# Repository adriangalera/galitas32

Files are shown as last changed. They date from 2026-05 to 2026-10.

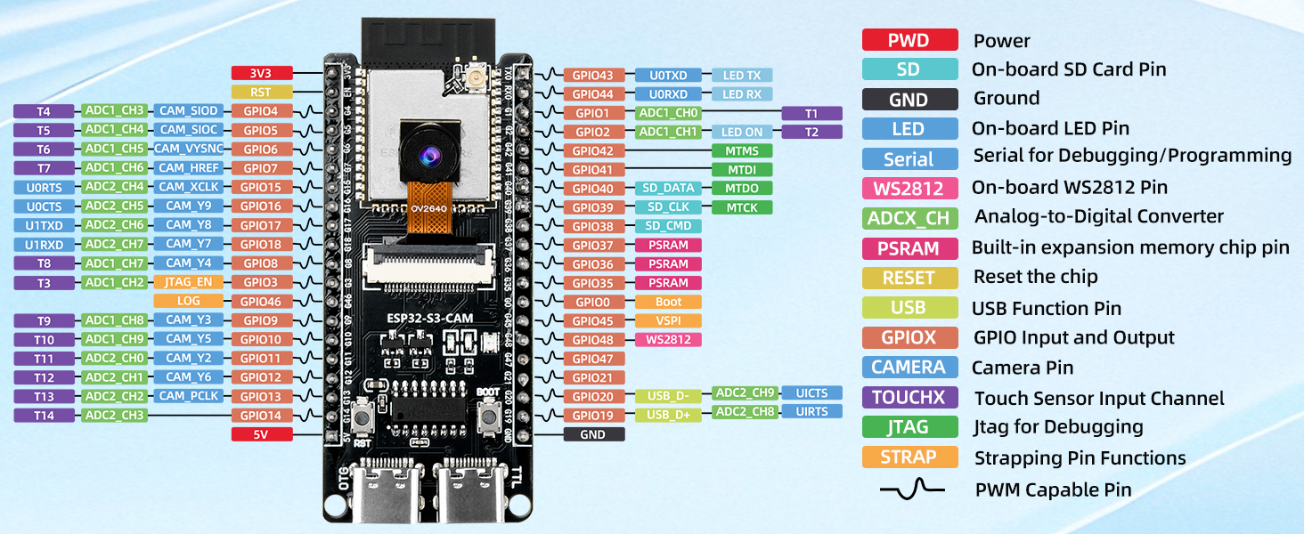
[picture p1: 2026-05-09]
pinout.jpg

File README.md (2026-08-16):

# galitas32

Home alarm built with ESP32

Features:

- Read door sensor
- Camera to store/send images
- Buzzer to scare burglars
- LED strip with programmable colors
- RFID to lock/unlock the alarm
- Connected to MQTT to interact with the system via telegram, through a Raspberry Pi acting as MQTT Broker and Telegram bot.

This is built using [ESP32-S3-CAM board](https://www.amazon.es/dp/B0F4D8ZY6L?ref=ppx_yo2ov_dt_b_fed_asin_title&th=1). 

Built with [PlatformIO](https://docs.platformio.org/en/latest/)

## Requirements

The physical mechanisms must work regardless of the network connection, i.e: door sensor, LED strip, camera, RFID reader and speaker. 

When the network is enabled, it will act as an enhacement.

> `*` optional steps (the alarm will still work without them)

### Startup procedure

1. Setup read sensor
2. Setup LED strip
3. Setup camera
4. Setup RFID reader
5. Setup speaker
6. `*`Setup Wifi
7. `*`Setup MQTT
8. Determine the lock status: armed/disarmed

### Door sensor

When the door is open:

- The LED strip is powered, the color depends on the lock status:
    - Armed: blinking red/blue like a policen siren
    - Disarmed: welcoming color: light orange or something like this

- Camera takes pictures for 30 seconds one picture each second:
    - Armed: send the pictures via MQTT (to telegram) and store the images in the SD
    - Disarmed: store the images in the SD

- Speaker: 
    - Armed: powered and making noises
    - Disarmed: do nothing

- `*` MQTT:
    - Armed: While open send message about door opened
    - Disarmed: While open send message about door opened

When the door is closed:

- LED strip: powered down
- Camera: stop take pictures task (if running)
- Speaker: powered down
- MQTT: stop sending message task

### RFID reader

The RFID read will be used to toogle the status and deactivate the alerting devices when the alarm is armed:

When the RFID tag is detected in the reader:
- Disarmed: 
    - Set the alarm in armed state
    - Send a message about the state toggling `*`

- Armed:
    - Set the alarm in disarmed state
    - Send a message about the state toggling `*`
    - The alerting devices will see the disarmed state

## Wirings

### Door sensor

```text

ESP32
-------
   Common GND -------------------------------+
                                             |
   D2 (input pin)                            |
        |                                    |
        |                                    |
        +--------------------[ REED SWITCH ]+
                             (magnet closes contact)
```

### LED Strip

```text

External 5V Power Supply
------------------------
    +5V ----------------------------+------------------> LED Strip +5V
                                    |
    GND ----------------------------+------------------> LED Strip GND
                                    |
                                    +------------------> Common GND

ESP32
-------
   D6 (data pin)
        |
        |   330Ω (recommended)
        +----/\/\/\/\-------------------------> DIN (LED Strip Data In)
```

There's an external power source providing 5V for the LED strip. The GND should be common with the ESP32 board.

The LED strip needs to be programmed through the Data In line. Therefore the output pin of the ESP32 will be connected to DIN port in the LED strip. The resistor protects the pin from current surges caused by the LED strip.

### Buzzer

```text
    ESP
    --------
        PIN 21
        |
        |   1kΩ
        +---/\/\/\----+
                        |
                        |
                    B |/
GND ---------------- |   TIP120
                    C |\ 
                        |
                        +--------(-) Buzzer (+)-------- +5V
                        |
                    E  |
                        |
                        GND
```

**Base**: connected with the ESP32 PIN via a 1K resistor for protection.

**Collector**: connected to the negative side of the buzzer. This acts as the switch to close the circuit when the base has signal coming from ESP32.

**Emitter**: connected to GND

## Case

The 3D design of the case it is AI-enabled. Make sure to install:

```bash
brew install admesh
pip3 install trimesh rtree scipy
```

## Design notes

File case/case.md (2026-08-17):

# Especificación completa para agente IA — Carcasa 3D para alarma ESP32-S3

Diseña una **carcasa imprimible en 3D para un sistema de alarma doméstico DIY basado en ESP32-S3**, destinada a ser modificada posteriormente en **Tinkercad** e impresa mediante FDM en una **Artillery Genius**.

Estas instrucciones consolidan las decisiones de diseño tomadas hasta ahora. **No deben revertirse decisiones ya establecidas**, especialmente la posición inferior de los conectores, los buses verticales separados, el sistema de cámara y la entrada inferior del cable USB.

El objetivo no es simplemente producir STL visualmente correctos: el conjunto debe ser **mecánicamente montable, desmontable, imprimible y verificable**.

---

# 1. Objetivo estético

La carcasa debe parecer un **detector fotográfico de alarma comercial montado en pared**, no una caja rectangular genérica para proyectos Arduino.

Puede utilizarse como inspiración general el lenguaje visual de detectores fotográficos de sistemas como Verisure/Securitas Direct, pero **sin copiar exactamente ningún producto comercial**.

Dimensiones exteriores objetivo aproximadas:

* Alto: **190 mm**
* Ancho: **74 mm**
* Profundidad: **44 mm**

Características visuales:

* Formato vertical
* Laterales redondeados
* Parte superior redondeada
* Parte inferior redondeada
* Frontal ligeramente convexo/suavizado
* Superficies exteriores limpias
* Cámara en la zona superior
* Sin electrónica visible
* Sin rejillas de ventilación visibles en el frontal
* Sin tornillos visibles desde el frontal
* Sin estructuras mecánicas sobresaliendo por la superficie frontal

Priorizar una apariencia de **producto de consumo terminado**.

---

# 2. Componentes principales

El diseño debe incluir como mínimo:

1. `front_shell.stl`
2. `rear_shell.stl`
3. `camera_cradle.stl`
4. `dupont_insert_2pin.stl`
5. `dupont_insert_3pin.stl`
6. `dupont_insert_4pin.stl`
7. `dupont_insert_6pin.stl`

También es recomendable incluir:

8. `dupont_insert_blank.stl`
9. `camera_angle_gauge.stl`

Debe entregarse además el archivo paramétrico:

`alarm_case.scad`

---

# 3. Arquitectura frontal/trasera

La carcasa se divide en dos piezas principales:

* Frontal desmontable
* Trasera fija

La arquitectura de mantenimiento debe permitir que **la trasera permanezca montada en la pared al abrir la alarma**.

La mayor parte de la electrónica debe permanecer en la trasera:

* ESP32-S3
* Buses +5 V y GND
* Conectores Dupont
* Cableado de periféricos
* Electrónica auxiliar
* Driver/MOSFET de sirena

El frontal debe contener principalmente:

* Cámara
* Cradle de cámara
* Mecanismo de ajuste

Idealmente, el único enlace eléctrico que debe permanecer entre frontal y trasera al abrir la caja es el **ribbon de la OV2640**.

---

# 4. Sistema de cierre

La carcasa debe cerrarse mediante:

* Dos ganchos superiores
* Dos tornillos M3 inferiores

Procedimiento:

1. Introducir los dos ganchos superiores del frontal en los catches de la trasera.
2. Girar/bascular el frontal hacia la posición cerrada.
3. Introducir dos tornillos M3 desde la parte trasera/inferior.
4. Los tornillos roscan en insertos térmicos M3 instalados en bosses del frontal.

Los ganchos deben **solaparse físicamente** con los catches.

No crear ganchos puramente decorativos que solamente queden cerca de los receptores.

Los tornillos M3 deben:

* Atravesar plástico sólido de la trasera
* Estar alineados con los bosses del frontal
* Tener las cabezas recesadas
* No ser visibles desde el frontal

---

# 5. Insertos térmicos

El usuario dispone de insertos térmicos:

* M2
* M2.5
* M3
* M4
* M5
* M6

Usar:

* **M3 para el cierre principal**
* **M2.5 para el mecanismo ajustable de cámara**

No asumir que el diámetro nominal del inserto es el diámetro correcto del agujero impreso.

Parametrizar explícitamente:

* `m3_clearance`
* `m3_insert_pilot`
* `m25_clearance`
* `m25_insert_pilot`, si se utiliza inserto en el mecanismo

---

# 6. Frontal

El frontal debe incluir:

* Apertura de cámara
* Dos ganchos superiores
* Dos bosses inferiores para M3
* Soportes internos de cámara

La superficie exterior debe permanecer limpia.

## Restricción crítica

**Ninguna geometría de soporte de cámara puede atravesar la superficie exterior frontal.**

Esto incluye:

* Pivot supports
* Bosses
* Brackets
* Locking slot
* Refuerzos
* Orejetas
* Tornillos

Todos deben permanecer detrás de la superficie interior.

La única penetración relacionada con la cámara será la **apertura óptica**.

---

# 7. Cámara OV2640

La cámara es una **OV2640** conectada mediante ribbon al ESP32-S3.

Debe apuntar hacia abajo porque el dispositivo estará instalado verticalmente en una pared.

Rango de ajuste:

* **10° downward mínimo**
* **20° downward posición nominal**
* **35° downward máximo**

El cradle debe poder detenerse en cualquier posición razonable dentro de ese intervalo mediante un tornillo de bloqueo.

---

# 8. Pivote de cámara

Utilizar un eje horizontal.

Debe existir:

* Soporte fijo izquierdo
* Cradle
* Soporte fijo derecho

Un tornillo/eje **M2.5** debe poder atravesar físicamente:

```text
soporte izquierdo
       ↓
     cradle
       ↓
soporte derecho
```

Los tres agujeros deben ser:

* Coaxiales
* Correctamente alineados
* Con holgura adecuada

No diseñar dos pivotes independientes que no compartan exactamente el mismo eje.

---

# 9. Bloqueo angular

El sistema de bloqueo debe existir en **un solo lateral**.

Utilizar:

* Slot curvo
* Tornillo M2.5

El lateral opuesto debe ser únicamente pivote.

No crear dos slots de bloqueo.

El slot debe:

* Tener el mismo centro geométrico que el pivote
* Seguir correctamente la dirección real de rotación
* Cubrir aproximadamente 10°–35°
* Tener suficiente material alrededor

---

# 10. Apertura óptica

No utilizar un túnel circular estrecho.

La abertura debe admitir el campo de visión de la cámara en todo el rango de movimiento.

Puede ser:

* Verticalmente alargada
* Ovalada
* Chamfered internamente
* Recesada

Debe comprobarse como mínimo a:

* 10°
* 15°
* 20°
* 25°
* 30°
* 35°

---

# 11. Ribbon OV2640

Debe existir una ruta realista para el ribbon.

No debe:

* Pasar por el eje del pivote
* Ser pinzado al cerrar la carcasa
* Rozar aristas afiladas
* Interferir con el tornillo de bloqueo
* Quedar excesivamente doblado
* Impedir el movimiento del cradle

Dejar suficiente volumen detrás/debajo de la cámara para formar una curva suave.

---

# 12. ESP32-S3

Controlador:

**ESP32-S3 WROOM N16R8 camera development board con OV2640**

Dimensiones aproximadas del PCB:

**57.1 × 28.2 mm**

No diseñar un pocket de fricción exacta.

Añadir holgura para:

* PCB
* Pines
* Headers
* Dupont
* USB-C
* microSD
* Ribbon
* Cableado

---

# 13. Cradle del ESP32

La placa debe estar montada en la **trasera**.

Utilizar un sistema desmontable mediante:

* Rails
* Clips
* Posts
* Retenedores equivalentes

El cradle central utilizado hasta ahora es conceptualmente válido.

La placa debe poder retirarse para mantenimiento.

No atraparla permanentemente entre estructuras impresas.

---

# 14. Acceso USB-C y microSD del ESP32

Aunque exista una entrada independiente para alimentación general, debe mantenerse espacio para acceder al:

* USB-C del ESP32
* microSD

Verificar físicamente que:

* Puede conectarse un cable USB-C
* Los buses no bloquean el conector
* Los Dupont no bloquean el conector
* La placa puede retirarse
* La microSD tiene espacio razonable para inserción/extracción

---

# 15. Organización general de la trasera

La distribución preferida de arriba hacia abajo es:

```text
┌─────────────────────────────┐
│     CATCHES / WALL MOUNT    │
│                             │
│        ZONA CÁMARA          │
│                             │
│ +5V       ESP32       GND   │
│  ║          │          ║    │
│  ║          │          ║    │
│  ║          │          ║    │
│  ║                     ║    │
│                             │
│    ZONA AUXILIAR/BUZZER     │
│                             │
│ [BAY] [BAY] [BAY] [BAY]    │
│                             │
│ M3      USB POWER      M3   │
└────────────┬────────────────┘
             │
             ▼
          cable USB
```

La representación es conceptual y puede ajustarse para evitar interferencias.

---

# 16. Eliminar elementos innecesarios

No volver a introducir las protuberancias extrañas presentes en versiones iniciales.

Evitar:

* Cable loops laterales voluminosos
* Shelves arbitrarios
* Bosses sin función
* Soportes decorativos
* Estructuras laterales innecesarias
* Grandes bandejas dedicadas a un único componente

Mantener el interior limpio.

---

# 17. Alimentación general

El sistema utilizará **5 V**.

No asumir que toda la corriente de los periféricos debe circular a través del ESP32.

Arquitectura:

```text
              ENTRADA 5 V
                  │
          ┌───────┴───────┐
          │               │
       BUS +5V         BUS GND
          │               │
    ┌─────┼─────┐    ┌────┼─────┐
    │     │     │    │    │     │
 ESP32  RFID   LED  ESP32 RFID  LED
          │               │
       DRIVER          SIRENA
```

El ESP32 es una rama de alimentación más.

---

# 18. Sirena

La corriente de una sirena no debe ser suministrada directamente por un GPIO.

Utilizar:

* MOSFET
* Transistor
* Driver equivalente

El GPIO solamente proporciona la señal de control.

Debe existir espacio interior para este pequeño circuito.

---

# 19. Buses de alimentación

La trasera debe incorporar soportes para dos buses independientes:

* `+5V`
* `GND`

Los buses deben estar dispuestos **verticalmente**.

Configuración consolidada:

* `+5V` en el lateral interior izquierdo
* `GND` en el lateral interior derecho

No colocar ambos buses juntos.

---

# 20. Separación física de buses

Separarlos tanto como sea razonable dentro de la carcasa.

Objetivo aproximado:

**55–60 mm entre ejes**, si la geometría lo permite.

La razón principal es mecánica y de seguridad:

* Evitar puentes de estaño
* Evitar cortos accidentales
* Evitar tocar simultáneamente ambos buses con herramientas
* Facilitar soldadura y mantenimiento

---

# 21. Orientación vertical

No colocar los buses horizontalmente.

Aprovechar la altura de aproximadamente 190 mm.

Conceptualmente:

```text
+5V                          GND
 ║                            ║
 ╠── ESP32 5V        ESP32 ───╣
 ║                            ║
 ╠── RFID 5V          RFID ───╣
 ║                            ║
 ╠── LED 5V            LED ───╣
 ║                            ║
 ╠── DRIVER          DRIVER ───╣
 ║                            ║
 ╚── etc.              etc. ───╣
```

Las señales pueden circular principalmente por la zona central.

---

# 22. Material de los buses

Los buses pueden realizarse mediante:

* Hilo de cobre rígido
* Barra fina de cobre
* Conductor rígido equivalente

No aplicar estaño directamente sobre la pared de PLA/PETG.

El plástico solamente debe proporcionar **soporte mecánico y aislamiento**.

---

# 23. Clips para buses

Crear pequeños clips integrados en la trasera.

Características:

* Aproximadamente 4–6 clips por bus
* Distribuidos verticalmente
* Separación aproximada 20–30 mm
* Apertura hacia el **centro de la carcasa**

La apertura hacia el centro permite colocar el conductor lateralmente:

```text
PARED             INTERIOR

│   ┌──
│   │ ●  ← cobre
│   └──
│
```

No utilizar una sucesión de agujeros cerrados que obligue a introducir el conductor longitudinalmente.

---

# 24. Parámetros del bus

Parametrizar:

* `bus_wire_diameter`
* `bus_wire_clearance`
* `bus_clip_spacing`
* `bus_left_position`
* `bus_right_position`
* `bus_start_height`
* `bus_end_height`

Valor inicial orientativo:

`bus_wire_diameter = 1.6 mm`

El usuario deberá poder cambiarlo después de medir el conductor real.

---

# 25. Longitud de los buses

No extenderlos hasta la parte superior de la carcasa si no es necesario.

Deben:

* Comenzar debajo de la zona de cámara
* Recorrer la zona útil de electrónica
* Terminar antes de la zona inferior donde puedan interferir con Dupont, USB o M3

---

# 26. Kit Dupont disponible

El usuario dispone de un kit estándar Dupont de **2.54 mm** que permite fabricar conectores mediante crimpado.

Dispone de:

* Terminales macho
* Terminales hembra
* Carcasas multipin

Por tanto, aprovechar **conectores Dupont eléctricos reales**.

---

# 27. Arquitectura de conectores externos

La solución preferida es:

### Periférico

Cable terminado en **conector Dupont macho multipin**.

### Carcasa

Conector **Dupont hembra multipin** sujeto mecánicamente mediante un insert impreso.

Conceptualmente:

```text
EXTERIOR                   INTERIOR

Periférico
    │
┌───────────┐
│ DUPONT    │
│ MACHO     │
└──●─●─●────┘
   ↓ ↓ ↓
┌──○─○─○────┐
│ DUPONT    │
│ HEMBRA    │
└───────────┘
█████████████ ← insert/retención impresa
    │ │ │
    │ │ └── señal
    │ └──── GND
    └────── +5V
```

---

# 28. Función del insert Dupont

El plástico impreso **no sustituye el conector Dupont**.

Su función es exclusivamente:

* Sujetar la carcasa Dupont hembra
* Evitar que se introduzca hacia dentro
* Evitar que salga hacia fuera
* Resistir las fuerzas de conexión/desconexión

Debe poder retirarse durante mantenimiento.

---

# 29. Inserts Dupont requeridos

Crear:

* 2P
* 3P
* 4P
* 6P

También es recomendable:

* Insert ciego

---

# 30. Bahías modulares

Preferir varias bahías con **geometría externa común**.

Cada bahía debería poder recibir distintos inserts.

Por ejemplo:

```text
[BAY 1] [BAY 2] [BAY 3] [BAY 4]
```

y cada una podría utilizar:

* 2P
* 3P
* 4P
* 6P
* Blank

si la solución mecánica lo permite.

---

# 31. Ubicación de Dupont

Esta decisión es obligatoria:

**Todos los conectores Dupont externos deben encontrarse en la parte inferior de la trasera.**

No colocarlos:

* Junto al ESP32
* En mitad de la carcasa
* En la zona superior
* Dispersos por los laterales

Los cables externos deben poder salir naturalmente hacia abajo.

---

# 32. Cableado de Dupont

Ejemplo RFID 6P:

```text
+5V  ─────────► BUS +5V
GND  ─────────► BUS GND
SCK  ─────────► ESP32
MOSI ─────────► ESP32
MISO ─────────► ESP32
CS   ─────────► ESP32
```

Los conductores de alimentación se dirigen a los laterales.

Las señales pueden subir por la zona central.

---

# 33. Entrada USB de alimentación

Debe existir una abertura específica para introducir desde el exterior el **cable USB utilizado como alimentación principal de 5 V**.

Esta entrada es independiente de:

* Los conectores Dupont
* El USB-C de programación del ESP32

---

# 34. Posición del USB de alimentación

Situar la entrada en la **parte inferior**, preferiblemente centrada aproximadamente entre los dos tornillos M3 cuando la geometría lo permita.

Conceptualmente:

```text
│ [DUPONT] [DUPONT] [DUPONT] │
│                             │
│ M3      USB POWER       M3  │
└────────────┬────────────────┘
             │
             ▼
           cable
```

El cable debe salir naturalmente hacia abajo.

---

# 35. Apertura USB

La abertura debe permitir introducir **la cabeza completa del conector USB**, no únicamente el diámetro del cable.

Valor inicial orientativo utilizado:

* Ancho: aproximadamente **16 mm**
* Alto: aproximadamente **10 mm**
* Holgura adicional: aproximadamente **0.8 mm**

Estos valores **no son definitivos**.

Deben quedar parametrizados porque el usuario medirá posteriormente su cable real.

Crear:

* `usb_cable_hole_width`
* `usb_cable_hole_height`
* `usb_cable_clearance`
* `usb_cable_hole_position`

---

# 36. Forma de la entrada USB

Preferir una abertura/muesca accesible desde la parte inferior en lugar de un simple agujero circular.

La sustitución del cable debe ser sencilla.

Evitar obligar al usuario a:

* Cortar el cable
* Desoldarlo para retirarlo
* Desmontar innecesariamente toda la electrónica

---

# 37. Strain relief USB

Incorporar alivio de tensión interior.

Solución preferida:

**dos pequeños puntos/loops/posts para una brida**.

La brida debe sujetar el cable después de entrar en la carcasa.

Así:

```text
exterior
   │
   │ cable
   ▼
[entrada USB]
   │
   ├────(brida)────┐
   │               │
   └───────────────┘
         │
         ├── +5V → bus +5V
         └── GND → bus GND
```

Un tirón exterior no debe transmitirse directamente a las soldaduras.

---

# 38. Entrada USB vs USB-C ESP32

Distinguir claramente:

### Entrada USB principal

Proporciona alimentación general de 5 V al sistema.

### USB-C ESP32

Se utiliza para:

* Programación
* Depuración
* Alimentación alternativa cuando proceda

El diseño no debe confundir ambos.

---

# 39. Buzzer SFM-27

Debe reservarse espacio para un buzzer aproximadamente:

**SFM-27, ~30 × 15 mm**

No utilizar únicamente sus dimensiones nominales.

Reservar un volumen aproximado de al menos:

**35 × 20 × 20 mm**

para incluir:

* Cuerpo
* Terminales
* Soldaduras
* Cables
* Holgura de montaje

---

# 40. Posición del buzzer

Preferir una zona libre:

* Entre cámara y ESP32, si existe suficiente profundidad
* O en otra zona interna libre que no interfiera con los buses

No bloquear:

* Cámara
* Ribbon
* ESP32
* USB-C
* microSD
* Dupont
* Buses

---

# 41. Retención del buzzer

No volver a crear una gran bandeja/shelf como en diseños anteriores.

Si se proporciona retención específica, utilizar algo mínimo:

* 2–3 pequeños clips
* Topes
* Clip + tope
* Sistema equivalente

El buzzer debe ser **desmontable**.

No pegarlo permanentemente ni atraparlo entre las dos mitades.

---

# 42. Validación específica del buzzer

Antes de finalizar, comprobar con un volumen de referencia de al menos:

**35 × 20 × 20 mm**

que:

* Cabe dentro de la carcasa cerrada
* No toca el frontal
* No toca la cámara
* No limita el ajuste 10°–35°
* No pinza el ribbon
* No interfiere con ESP32
* No bloquea USB-C
* No bloquea microSD
* No toca los buses
* Sus cables tienen una ruta plausible

No declarar simplemente que “hay espacio” basándose en observación visual.

---

# 43. Montaje en pared

Usar un sistema sencillo.

Preferido:

* Keyhole superior
* Agujero secundario pequeño antirotación

Evitar grandes brackets externos.

Debe ser compatible con mantener la trasera instalada mientras se abre el frontal.

---

# 44. Printabilidad

Diseñar para aproximadamente:

* Boquilla: **0.4 mm**
* Layer height: **0.2 mm**
* Material: PLA o PETG

PETG puede utilizarse especialmente para:

* Ganchos
* Clips
* Retenedores Dupont
* Clips de buses

Evitar:

* Paredes extremadamente finas
* Clips frágiles
* Overhangs innecesarios
* Soportes de impresión excesivos
* Geometría interna imposible de imprimir

---

# 45. Compatibilidad Tinkercad

Todos los STL deben:

* Utilizar mm
* Importar a escala **100 %**
* Tener geometría limpia
* Ser manifold
* Ser watertight
* Evitar polygon counts absurdamente altos
* Poder posicionarse fácilmente
* Estar separados por componente funcional

No crear una única STL con todo el conjunto fusionado.

---

# 46. Parametrización OpenSCAD

Entregar:

`alarm_case.scad`

Los parámetros principales deben estar agrupados al comienzo del archivo.

Como mínimo:

```text
case_height
case_width
case_depth
wall_thickness

m3_clearance
m3_insert_pilot

m25_clearance
m25_insert_pilot

camera_min_angle
camera_nominal_angle
camera_max_angle

camera_pivot_x
camera_pivot_y
camera_pivot_z

camera_aperture_width
camera_aperture_height

pcb_width
pcb_height
pcb_clearance

dupont_pitch
dupont_fit_clearance
dupont_bay_width
dupont_bay_height

bus_wire_diameter
bus_wire_clearance
bus_clip_spacing
bus_left_position
bus_right_position
bus_start_height
bus_end_height

usb_cable_hole_width
usb_cable_hole_height
usb_cable_clearance
usb_cable_hole_position

buzzer_width
buzzer_height
buzzer_depth
buzzer_clearance

clip_clearance
```

No esconder dimensiones críticas dentro de módulos difíciles de encontrar.

---

# 47. Validación de la cámara

Comprobar el conjunto ensamblado a:

* 10°
* 15°
* 20°
* 25°
* 30°
* 35°

En cada posición verificar:

* Cradle vs frontal
* Cámara vs frontal
* Apertura óptica
* Ribbon
* Tornillo de bloqueo
* Buzzer
* Otros elementos internos

---

# 48. Validación del pivote

Comprobar explícitamente:

* Coaxialidad
* Diámetro de paso
* M2.5 atravesando ambos soportes
* M2.5 atravesando cradle
* Ausencia de plástico bloqueando el eje

No inferirlo solamente de las coordenadas CAD.

---

# 49. Validación del cierre

Comprobar:

* Enganche físico de ambos hooks
* Profundidad de solape
* Ausencia de interferencia de shells
* Alineación de ambos M3
* Agujeros M3 atravesando material sólido
* Bosses correctamente posicionados
* Acceso de herramienta a las cabezas

---

# 50. Validación Dupont

Comprobar:

* Inserts caben en sus bays
* No pueden empujarse hacia dentro al conectar
* No salen al desconectar
* Hay espacio para el conector macho externo
* El cable puede salir hacia abajo
* No interfieren con M3
* No interfieren con USB power
* No bloquean PCB
* No bloquean buses

---

# 51. Validación de buses

Comprobar:

* Bus +5 V cabe
* Bus GND cabe
* Separación física suficiente
* Clips imprimibles
* Conductor insertable lateralmente
* Conductor extraíble
* Acceso con soldador razonable
* No interferencia con ESP32
* No interferencia con buzzer
* No interferencia con Dupont
* No interferencia con USB-C
* No interferencia con microSD
* No interferencia con cámara

---

# 52. Validación USB power

Comprobar:

* La cabeza del conector objetivo atraviesa la abertura
* El cable sale hacia abajo
* No existe radio de curvatura excesivamente pequeño
* Existe espacio para la brida
* La brida puede instalarse
* El cable no queda pinzado por el frontal
* No debilita excesivamente la zona de M3
* Puede sustituirse
* No interfiere con Dupont

---

# 53. Validación de malla

Para cada STL comprobar:

* Watertight
* Manifold
* Winding consistente
* Ausencia de caras degeneradas relevantes
* Ausencia de geometrías flotantes
* Una sola pieza conectada cuando corresponda

Especialmente:

* Front
* Rear
* Camera cradle
* Cada Dupont insert
* Blank insert
* Gauge

---

# 54. Cama de impresión

Comprobar que cada componente individual cabe en la cama de una **Artillery Genius**.

No asumirlo únicamente por las dimensiones nominales exteriores.

Considerar orientación real de impresión.

---

# 55. Informe de validación

Entregar un:

`validation_report.txt`

o equivalente.

No escribir únicamente:

`Validation passed`

Debe detallar qué se comprobó.

Ejemplo:

```text
Rear shell:
- Watertight: PASS
- Manifold: PASS
- Connected components: 1
- USB opening clearance: PASS
- Bus clips: PASS

Camera:
- 10 deg: PASS
- 15 deg: PASS
- 20 deg: PASS
- 25 deg: PASS
- 30 deg: PASS
- 35 deg: PASS

Buzzer envelope 35x20x20:
- Front collision: PASS
- Camera collision: PASS
- PCB collision: PASS
...
```

---

# 56. README

Incluir un `README.md` explicando:

* Qué archivo es cada pieza
* Orientación recomendada de impresión
* Hardware necesario
* M3 utilizados
* M2.5 utilizados
* Cómo instalar insertos térmicos
* Cómo montar la cámara
* Cómo montar los Dupont
* Cómo instalar los buses
* Cómo sujetar el cable USB
* Cómo montar el buzzer
* Orden de montaje de la carcasa

---

# 57. Bundle final

Empaquetar todo en:

`alarm_case_bundle.zip`

Debe contener como mínimo:

```text
alarm_case.scad

front_shell.stl
rear_shell.stl
camera_cradle.stl

dupont_insert_2pin.stl
dupont_insert_3pin.stl
dupont_insert_4pin.stl
dupont_insert_6pin.stl

README.md
validation_report.txt
```

Opcional/recomendado:

```text
dupont_insert_blank.stl
camera_angle_gauge.stl
```

---

# 58. Decisiones consolidadas que NO deben revertirse

Las siguientes decisiones proceden de iteraciones anteriores y deben considerarse requisitos:

* Aspecto de detector de alarma comercial
* Aproximadamente 190 × 74 × 44 mm
* Dos shells
* Frontal limpio
* Cámara arriba
* Cámara ajustable 10°–35°
* Posición nominal ~20°
* M2.5 para cámara
* Un único locking slot lateral
* Pivot holes coaxiales
* M3 para cierre de carcasa
* Dos hooks superiores funcionales
* Dos M3 inferiores
* ESP32 desmontable
* ESP32 en la trasera
* Sin gran abertura rectangular trasera
* Sin extrañas protuberancias laterales
* Sin cable loops voluminosos
* Dupont agrupados abajo
* Dupont eléctricos reales del kit
* Inserts impresos únicamente como soporte mecánico
* Buses de cobre independientes
* Bus +5 V vertical en un lateral
* Bus GND vertical en el lateral contrario
* Máxima separación práctica entre buses
* Clips de bus abiertos hacia el centro
* Alimentación de periféricos directamente desde los buses cuando corresponda
* No obligar a que toda la corriente atraviese el ESP32
* Entrada independiente de cable USB de alimentación
* Entrada USB en la zona inferior
* Strain relief interno mediante brida o equivalente
* Mantener acceso al USB-C del ESP32
* Reservar espacio real para SFM-27
* No utilizar una gran bandeja dedicada al buzzer
* Buzzer desmontable
* Reservar aproximadamente 35 × 20 × 20 mm para buzzer + conexiones
* Validar todas las piezas antes de entregar

---

# Prioridad final

El resultado debe ser una carcasa que tenga sentido tanto **cerrada como abierta**.

Cerrada debe parecer un producto comercial.

Abierta debe mostrar una arquitectura ordenada y fácil de mantener:

```text
          CÁMARA

+5V        ESP32         GND
 ║           │            ║
 ║       señales          ║
 ║                        ║

      BUZZER / DRIVER

   DUPONT MODULARES

M3      USB POWER       M3
```

No sacrificar la capacidad real de montaje por conseguir una geometría visualmente atractiva.

**Antes de entregar cualquier STL, verificar el ensamblaje completo y las interferencias reales entre componentes.**

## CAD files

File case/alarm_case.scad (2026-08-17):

// DIY ESP32 Alarm / Photo-Detector Enclosure
// Parametric OpenSCAD source, dimensions in mm.
// Designed for 0.4 mm nozzle / 0.2 mm layers, PLA or PETG.
$fn = 48;

PART = "assembly"; // front, rear, camera_cradle, dupont_2, dupont_3, dupont_4, dupont_6, angle_gauge, assembly

// ---------------- User-tunable parameters ----------------
case_w = 74;
case_d = 44;
case_h = 190;
corner_r = 11;
wall = 2.4;
seam_y = 0;

camera_z = 48;
camera_pivot_y = -5.8;
camera_module_w = 24.5;    // generous OV2640 PCB envelope
camera_module_h = 24.5;
camera_cradle_w = 29.0;
camera_cradle_h = 30.0;
pivot_clearance_d = 2.9;   // M2.5 bolt clearance
lock_clearance_d = 2.9;
lock_radius = 10.5;
cam_min_angle = 10;
cam_nom_angle = 20;
cam_max_angle = 35;

m3_screw_clearance = 3.4;
m3_insert_pilot_d = 4.2;   // intentionally easy to tune for your actual heat-set insert
m3_boss_d = 9.5;
m3_z = -71;
m3_x = 20;

bay_w = 18;
bay_h = 10;
bay_cut_w = 17.8;
bay_cut_h = 9.8;
bay_z = -57;   // moved to lower rear section, above closure screws
bay_xs = [-22, 0, 22];
header_pitch = 2.54;
header_hole = 1.25;

// Vertical 5 V / GND bus supports on rear shell
bus_x = 29.0;             // buses are separated across almost the full enclosure width
bus_y = 15.7;             // wire center, behind PCB and clear of the shell seam
bus_z_min = -41;          // stops above Dupont connector zone
bus_z_max = 30;           // stops below camera mechanism
bus_wire_d = 1.6;         // tune for the copper wire / rod actually used
bus_wire_clearance = 0.45;
bus_clip_zs = [-38,-20,-2,16,28];

// Main 5 V USB power cable entry, centered at the bottom rear edge.
// Sized to pass a typical USB plug; tune to the actual cable before printing.
usb_entry_w = 16.0;
usb_entry_h = 10.0;
usb_entry_clearance = 0.8;
usb_entry_x = 0;
usb_entry_z = -92.0;
usb_strain_relief_z = -81.5;
usb_strain_relief_x = 7.5;
usb_zip_tie_slot_w = 3.2;
usb_zip_tie_slot_h = 7.0;

// ---------------- Utility geometry ----------------
module rounded_profile_2d(w,h,r) {
    offset(r=r) square([w-2*r,h-2*r],center=true);
}

module rounded_prism_y(w,d,h,r) {
    rotate([90,0,0]) linear_extrude(height=d,center=true,convexity=10) rounded_profile_2d(w,h,r);
}

module soft_body(w,d,h,r) {
    // Slightly softened/convex consumer-product profile with tapered front/rear edges.
    hull() {
        translate([0,-d/2+0.7,0]) rounded_prism_y(w-1.6,1.4,h-1.6,max(2,r-0.8));
        translate([0,-d/2+3.0,0]) rounded_prism_y(w,1.2,h,r);
        translate([0, d/2-3.0,0]) rounded_prism_y(w,1.2,h,r);
        translate([0, d/2-0.7,0]) rounded_prism_y(w-1.2,1.4,h-1.2,max(2,r-0.6));
    }
}

module hole_x(d=3, len=10) { rotate([0,90,0]) cylinder(d=d, h=len, center=true); }
module hole_y(d=3, len=10) { rotate([90,0,0]) cylinder(d=d, h=len, center=true); }

module shell_skin() {
    difference() {
        soft_body(case_w,case_d,case_h,corner_r);
        soft_body(case_w-2*wall, case_d-2*wall, case_h-2*wall, max(2,corner_r-wall));
    }
}

module front_skin() {
    intersection() {
        shell_skin();
        translate([0,-case_d/4-0.1,0]) cube([case_w+4,case_d/2+0.2,case_h+4],center=true);
    }
}

module rear_skin() {
    intersection() {
        shell_skin();
        translate([0,case_d/4+0.1,0]) cube([case_w+4,case_d/2+0.2,case_h+4],center=true);
    }
}

// ---------------- Front shell internal mechanics ----------------
module camera_aperture_cut() {
    // Wide/tall rounded opening avoids a restrictive circular tunnel.
    translate([0,-case_d/2+0.5,camera_z])
        rounded_prism_y(22,8,42,3.5);
}

module arc_slot_x(r=lock_radius, a0=cam_min_angle, a1=cam_max_angle, d=3.2, len=8) {
    // Slot lies in Y-Z plane, axis through X.
    for (a=[a0:2:a1-2]) hull() {
        translate([0, r*cos(a), r*sin(a)]) hole_x(d,len);
        translate([0, r*cos(a+2), r*sin(a+2)]) hole_x(d,len);
    }
}

module camera_supports() {
    // Fixed ears and ribs remain well behind the front inner surface.
    support_x = camera_cradle_w/2 + 2.2;
    ear_t = 4.0;
    ear_y = camera_pivot_y;
    ear_z = camera_z;
    for (sx=[-1,1]) {
        x0=sx*support_x;
        difference() {
            union() {
                translate([x0,ear_y,ear_z]) rotate([0,90,0]) cylinder(d=13,h=ear_t,center=true);
                // Left side only: fixed locking plate covering the 10-35 degree arc.
                if (sx < 0) hull() {
                    translate([x0, ear_y+lock_radius*cos(cam_min_angle), ear_z+lock_radius*sin(cam_min_angle)]) rotate([0,90,0]) cylinder(d=8,h=ear_t,center=true);
                    translate([x0, ear_y+lock_radius*cos(cam_max_angle), ear_z+lock_radius*sin(cam_max_angle)]) rotate([0,90,0]) cylinder(d=8,h=ear_t,center=true);
                    translate([x0,ear_y,ear_z]) rotate([0,90,0]) cylinder(d=8,h=ear_t,center=true);
                }
                // printable rib back to the front wall, entirely internal
                hull() {
                    translate([x0, -18.8, ear_z+2]) cube([ear_t,3.0,11],center=true);
                    translate([x0, ear_y, ear_z]) cube([ear_t,4,9],center=true);
                }
            }
            translate([x0,ear_y,ear_z]) hole_x(pivot_clearance_d,ear_t+2);
            // Only LEFT side has the curved locking slot.
            if (sx < 0)
                translate([x0,ear_y,ear_z]) arc_slot_x(lock_radius,cam_min_angle,cam_max_angle,lock_clearance_d+0.35,ear_t+2);
        }
    }
}

module front_m3_bosses() {
    for (x=[-m3_x,m3_x])
        translate([x,-10.5,m3_z])
        difference() {
            rotate([90,0,0]) cylinder(d=m3_boss_d,h=20.4,center=true);
            // blind pilot from rear-facing end; leaves solid plastic toward front exterior
            translate([0,3.6,0]) rotate([90,0,0]) cylinder(d=m3_insert_pilot_d,h=14.8,center=true);
        }
}

module front_upper_hooks() {
    // Two real seam-crossing hooks. Front half extends through Y=0 into rear catch volume.
    for (x=[-20,20]) {
        union() {
            translate([x,-3.0,76]) cube([8,6,4],center=true);
            translate([x,1.25,78.2]) cube([8,2.8,4.4],center=true); // barb across seam
            hull() {
                translate([x,-18.6,74]) cube([8,3.0,4],center=true);
                translate([x,-3.0,76]) cube([8,2,4],center=true);
            }
        }
    }
}

module front_shell() {
    difference() {
        union() {
            front_skin();
            camera_supports();
            front_m3_bosses();
            front_upper_hooks();
        }
        camera_aperture_cut();
    }
}

// ---------------- Rear shell mechanics ----------------
module rear_catches() {
    // Catch roof + side walls overlap the front hook barbs across the seam.
    for (x=[-20,20])
        difference() {
            union() {
                translate([x,3.1,80.6]) cube([11,6.2,3.4],center=true);
                translate([x-4.8,3.1,77.8]) cube([1.8,6.2,7.5],center=true);
                translate([x+4.8,3.1,77.8]) cube([1.8,6.2,7.5],center=true);
            }
            translate([x,1.2,78.1]) cube([9.4,4.0,4.8],center=true); // receiving pocket
        }
    // rear-wall bridges keep catches integral while leaving hook pocket open
    for (x=[-20,20]) hull() {
        translate([x,5.5,82.0]) cube([8,2,2.4],center=true);
        translate([x,19.0,82.0]) cube([8,2.8,2.4],center=true);
    }
}

module rear_m3_pads() {
    for (x=[-m3_x,m3_x])
        translate([x,10.6,m3_z]) rotate([90,0,0]) cylinder(d=11.5,h=21.0,center=true);
}

module rear_m3_holes() {
    for (x=[-m3_x,m3_x]) {
        translate([x,10.5,m3_z]) rotate([90,0,0]) cylinder(d=m3_screw_clearance,h=25,center=true);
        // recessed screw head from rear face, not visible from front
        translate([x,19.0,m3_z]) rotate([90,0,0]) cylinder(d=6.7,h=7.0,center=true);
    }
}

module keyhole_cut(z=40) {
    translate([0,case_d/2-0.2,z]) {
        hole_y(4.4,7);
        translate([0,0,5]) hull() {
            hole_y(4.4,7);
            translate([0,0,5]) hole_y(7.5,7);
        }
    }
}

module anti_rotation_hole(z=43) {
    // Small secondary wall screw / locating hole below the main keyhole.
    translate([0,case_d/2-0.2,z]) hole_y(4.0,7);
}

module dupont_bay_cut(x=0,z=0) {
    translate([x,case_d/2-1.0,z]) cube([bay_cut_w,6,bay_cut_h],center=true);
}
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

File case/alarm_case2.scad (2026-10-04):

// DIY ESP32 Alarm / Photo-Detector Enclosure
// Parametric OpenSCAD source, dimensions in mm.
// Designed for 0.4 mm nozzle / 0.2 mm layers, PLA or PETG.
$fn = 48;

PART = "exploded"; // front, rear, wall_mount, pcb2, assembly, wall_assembly, exploded
// Camera stays on the ESP32-S3-CAM board, facing -Y (USB connectors downward).
// No independent camera tilt: the original short ribbon stays in its natural position.
// The front cover must not pull, clamp or carry the camera when removed.
// Use the board's existing camera retention; this cover does not retain a loose sensor.
// Photo-based optical alignment is provisional: check against the real board before printing.

// ---------------- User-tunable parameters ----------------
case_w = 74;
case_d = 44;
case_h = 190;
corner_r = 11;
wall = 2.4;
// Shared rail dimensions: the rear rim follows the front edge of the rails.
pcb_rail_y = 9.5;
pcb_rail_depth = 25;
seam_y = min(0, pcb_rail_y - pcb_rail_depth/2); // -3 mm; rear half depth = 25 mm

// PCB reference matches the existing 60 mm rail channels, not a measured board.
pcb_reference_w = 28;              // existing project value
pcb_reference_h = 60;              // provisional occupied channel height
pcb_reference_z = -3;
pcb_slot_y_offset = -8.5;
pcb_reference_y = pcb_rail_y + pcb_slot_y_offset;

// Lens is over the upper portion of the PCB, as in the supplied photograph.
// Estimated offset; change this value if the lens is higher/lower on your board.
camera_from_pcb_top = 14;
camera_x = 0;
camera_z = pcb_reference_z + pcb_reference_h/2 - camera_from_pcb_top;
// Broad, shallow window tolerates alignment uncertainty and lens setback.
// Actual field of view still depends on the lens; no optical specification is assumed.
camera_window_w = 40;
camera_window_h = 40;
camera_window_r = 4;
show_electronics = true;            // assembly preview only, never exported to STL
camera_preview_projection = 7;    // illustrative projection from PCB, not measured

// ---------------- Fixed downward wall mount ----------------
wall_tilt = 20;                   // degrees downward; change and reprint (10..35)
screw_above_frame = 85;           // measured vertical screw-to-frame-top distance
door_vertical_clearance = 85;     // frame top to door collision limit
door_safety_clearance = 5;        // minimum reserved vertical gap above that limit
frame_projection = 14;            // ASSUMED protrusion from wall; user described frame width
frame_clearance = 4;              // allowance around the frame
// Conservative bound keeps the complete case clear of the frame below the screw.
wall_bottom_clearance = (frame_projection+frame_clearance)/cos(wall_tilt)+1;
mount_rib_x = 30;
mount_rib_t = 4;
mount_z_max = 78;
mount_plate_t = 4;
mount_screw_shank_d = 4.5;         // clearance for a nominal 4 mm wall screw
mount_screw_head_d = 9;            // entry clearance; head must be wider than shank slot
mount_head_space = 4;             // free depth behind retaining plate
wall_plane_y = case_d/2 + case_h/2*tan(wall_tilt) + wall_bottom_clearance;
// Position screw seat from the conservative bounding box of the tilted case.
// This automatically raises the case enough to clear the door with margin.
case_bottom_below_wall_origin = case_h/2*cos(wall_tilt)
    + case_d/2*sin(wall_tilt) + wall_plane_y*sin(wall_tilt);
mount_seat_z = screw_above_frame + door_vertical_clearance
    - door_safety_clearance - case_bottom_below_wall_origin;
mount_entry_z = mount_seat_z-13;   // entry below seat; lower case to lock
mount_plate_z = mount_seat_z-3;
frame_top_z = mount_seat_z-screw_above_frame; // wall-frame coordinates
mount_pad_h = 12;
mount_pad_z = frame_top_z+frame_clearance+mount_pad_h/2+1;
mount_z_min = (mount_pad_z-8)*cos(wall_tilt)-10;

// Wall plane in enclosure coordinates: y = wall_plane_y + z*tan(wall_tilt).
// Thick end at TOP: rotation +wall_tilt about X points the camera DOWN.

// Mounting: insert screw head in the LOWER round opening, then lower the case.
// Start with about 4.5 mm between wall and underside of screw head; adjust to fit.
// The two lower pads may receive thin non-slip pads of equal thickness.
// Mount prints separately; verify slicer support needs for the selected orientation.

// ---------------- Separate mount / PLA weld joints ----------------
joint_plane_y = case_d/2+4;        // mating plane; installed mount position unchanged
joint_zs = [-20,60];              // four pads: two per side
joint_w = 10;
joint_h = 20;
joint_bevel = 0.7;                // paired bevels form a perimeter welding groove
joint_clearance = 0.25;           // socket clearance per side
joint_pin_depth = 2.5;
joint_screw_d = 3.4;              // two optional M3 through-bolts, upper pads only
// Assemble dry: four rear pins into four blind mount sockets, faces seated.
// Tack opposite corners, then fill exposed perimeter grooves with matching PLA.
// Do not melt locating pins before alignment; allow the complete joint to cool.
// Optional upper through-bolts use nuts inside the empty rear shell.
// Select wall_mount for a separate part placed flat on its joint faces at Z=0.

m3_screw_clearance = 3.4;
m3_insert_pilot_d = 4.2;   // intentionally easy to tune for your actual heat-set insert
m3_boss_d = 9.5;
m3_z = -71;
m3_x = 20;

bay_w = 18;
bay_h = 10;
bay_cut_w_2pin = 5.50;
bay_cut_w_3pin = 8;
bay_cut_w_5pin = 16;
bay_cut_w_8pin = 21;
bay_cut_h = 3;
bay_z = -57;   // moved to lower rear section, above closure screws
bay_xs = [-22, 0, 22];
header_pitch = 2.54;
header_hole = 1.25;

// Vertical 5 V / GND bus supports on rear shell
bus_x = 29.0;             // buses are separated across almost the full enclosure width
bus_y = 15.7;             // wire center, behind PCB and clear of the shell seam
bus_z_min = -41;          // stops above Dupont connector zone
bus_z_max = 30;           // stops below camera mechanism
bus_wire_d = 1.6;         // tune for the copper wire / rod actually used
bus_wire_clearance = 0.45;
bus_clip_zs = [-38,-20,-2,16,28];

// Main 5 V USB power cable entry, centered at the bottom rear edge.
// Sized to pass a typical USB plug; tune to the actual cable before printing.
usb_entry_w = 16.0;
usb_entry_h = 10.0;
usb_entry_clearance = 0.8;
usb_entry_x = 0;
usb_entry_z = -92.0;
usb_strain_relief_z = -81.5;
usb_strain_relief_x = 7.5;
usb_zip_tie_slot_w = 3.2;
usb_zip_tie_slot_h = 7.0;

// ---------------- Utility geometry ----------------
module rounded_profile_2d(w,h,r) {
    offset(r=r) square([w-2*r,h-2*r],center=true);
}

module rounded_prism_y(w,d,h,r) {
    rotate([90,0,0]) linear_extrude(height=d,center=true,convexity=10) rounded_profile_2d(w,h,r);
}

module soft_body(w,d,h,r) {
    // Slightly softened/convex consumer-product profile with tapered front/rear edges.
    hull() {
        translate([0,-d/2+0.7,0]) rounded_prism_y(w-1.6,1.4,h-1.6,max(2,r-0.8));
        translate([0,-d/2+3.0,0]) rounded_prism_y(w,1.2,h,r);
        translate([0, d/2-3.0,0]) rounded_prism_y(w,1.2,h,r);
        translate([0, d/2-0.7,0]) rounded_prism_y(w-1.2,1.4,h-1.2,max(2,r-0.6));
    }
}

module hole_x(d=3, len=10) { rotate([0,90,0]) cylinder(d=d, h=len, center=true); }
module hole_y(d=3, len=10) { rotate([90,0,0]) cylinder(d=d, h=len, center=true); }

module shell_skin() {
    difference() {
        soft_body(case_w,case_d,case_h,corner_r);
        soft_body(case_w-2*wall, case_d-2*wall, case_h-2*wall, max(2,corner_r-wall));
    }
}

module front_skin() {
    intersection() {
        shell_skin();
        translate([0,(seam_y-case_d/2-2)/2,0])
            cube([case_w+4,seam_y+case_d/2+2,case_h+4],center=true);
    }
}

module rear_skin() {
    intersection() {
        shell_skin();
        translate([0,(seam_y+case_d/2+2)/2,0])
            cube([case_w+4,case_d/2+2-seam_y,case_h+4],center=true);
    }
}

// ---------------- Front shell internal mechanics ----------------
module camera_aperture_cut() {
    // Through the front wall only; no internal tunnel or separate camera cradle.
    translate([camera_x,-case_d/2+0.5,camera_z])
        rounded_prism_y(camera_window_w,2*wall+4,camera_window_h,camera_window_r);
}

module front_m3_bosses() {
    for (x=[-m3_x,m3_x])
        translate([x,-10.5,m3_z])
        difference() {
            rotate([90,0,0]) cylinder(d=m3_boss_d,h=20.4,center=true);
            // blind pilot from rear-facing end; leaves solid plastic toward front exterior
            translate([0,3.6,0]) rotate([90,0,0]) cylinder(d=m3_insert_pilot_d,h=14.8,center=true);
        }
}
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

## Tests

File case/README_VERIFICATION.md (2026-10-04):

# Verificación local de `alarm_case.scad`

Estos scripts reproducen de forma automatizable las comprobaciones del ZIP: exportación CGAL con OpenSCAD, QA topológica de STL y varias comprobaciones estructurales/collisions.

## Requisitos (Windows)

- OpenSCAD instalado, normalmente en `C:\Program Files\OpenSCAD\openscad.exe`.
- Python 3.10+.
- PowerShell.

Pon esta carpeta junto a `alarm_case.scad` y, opcionalmente, `qa_mesh_v4.json`.

## Ejecución rápida

```powershell
Set-ExecutionPolicy -Scope Process Bypass
.\run_verification.ps1 -Scad .\alarm_case.scad -OpenSCAD "C:\Program Files\OpenSCAD\openscad.exe"
```

Si `openscad.exe` ya está en `PATH`, basta:

```powershell
.\run_verification.ps1 -Scad .\alarm_case.scad
```

El script crea `.venv`, instala `trimesh`, exporta los STL y deja los resultados en `verification_output`.

## Qué genera

- `verification_output/stl/*.stl`: piezas exportadas desde `PART`.
- `structure_report_local.txt`: comprobaciones de USB, buses, M3, pivote, cámara 10/15/20/25/30/35°, unión de clips/strain-relief, etc.
- `mesh_report_local.txt`: watertight, manifold edges, winding, componentes conectados, caras degeneradas, dimensiones y cama de impresión.
- `qa_structure_local.json` y `qa_mesh_local.json`: resultados en formato máquina.

## Exportar solamente los STL

```powershell
python .\export_parts.py --scad .\alarm_case.scad --out .\stl --openscad "C:\Program Files\OpenSCAD\openscad.exe"
```

La llamada a OpenSCAD se hace como argumento separado:

```text
-D PART="front"
```

Esto evita los problemas de comillas típicos de PowerShell al intentar escribir manualmente `-D PART=...`.

## Verificar solamente las mallas

```powershell
python .\verify_meshes.py --stl-dir .\stl --reference .\qa_mesh_v4.json
```

La cama por defecto es 220 x 220 x 250 mm (Artillery Genius). Puedes cambiarla:

```powershell
python .\verify_meshes.py --stl-dir .\stl --bed 220 220 250
```

## Verificar solamente la estructura SCAD

```powershell
python .\verify_structure.py --scad .\alarm_case.scad --openscad "C:\Program Files\OpenSCAD\openscad.exe"
```

Las pruebas CGAL generan intersecciones temporales para comprobar, entre otras cosas:

- cradle vs frontal en 10°, 15°, 20°, 25°, 30° y 35°;
- paso coaxial M2.5 por soportes y cradle;
- paso de los dos M3 por la trasera;
- paso de la abertura USB y salida hacia abajo;
- unión física de strain-relief y clips de bus con la pared trasera;
- hooks del frontal cruzando el plano de unión.

También valida relaciones paramétricas: separación de buses, zonas Z de buses/Dupont/cámara/M3, rango angular y posición de USB.

## Límites importantes

Estas pruebas verifican geometría CAD y malla, pero no pueden certificar por sí solas:

- que tu conector USB físico real pase por el hueco;
- tolerancias reales de tu impresora/material;
- ajuste real de insertos térmicos M3/M2.5;
- flexibilidad/radio real del ribbon de cámara;
- acceso real del soldador con todos los cables montados.

Esas comprobaciones requieren medir el hardware y, para el cierre/encajes críticos, una impresión de prueba.

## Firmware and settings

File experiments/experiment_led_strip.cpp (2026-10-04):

#include <Adafruit_NeoPixel.h>

#define LED_PIN    20
#define LED_COUNT  60

Adafruit_NeoPixel strip(LED_COUNT, LED_PIN, NEO_GRB + NEO_KHZ800);

void setup() {

    Serial.begin(115200);
    Serial.println("===== APPLICATION STARTED =====");

    strip.begin();
    strip.clear();
    strip.show();

    Serial.println("Setup complete ...");
}

void loop() {

    // Turn all LEDs ON
    for (int i = 0; i < LED_COUNT; i++) {
        strip.setPixelColor(i, strip.Color(255, i * 2, 0));
    }

    strip.show();

    delay(1000);

    // Turn all LEDs OFF
    strip.clear();
    strip.show();

    delay(1000);

    Serial.println("Blinking complete ...");
}

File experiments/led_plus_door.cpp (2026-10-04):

#include <Arduino.h>
#include <Adafruit_NeoPixel.h>

// ---------------- Door sensor ----------------
#define DOOR_SENSOR_PIN 19

// ---------------- LED strip ----------------
#define LED_PIN         20
#define LED_COUNT       60

Adafruit_NeoPixel strip(
    LED_COUNT,
    LED_PIN,
    NEO_GRB + NEO_KHZ800
);


// --------------------------------------------------
// Set all LEDs to the same color
// --------------------------------------------------
void setLedColor(uint8_t red, uint8_t green, uint8_t blue)
{
    for (int i = 0; i < LED_COUNT; i++)
    {
        strip.setPixelColor(
            i,
            strip.Color(red, green, blue)
        );
    }

    strip.show();
}


// --------------------------------------------------
// Setup
// --------------------------------------------------
void setup()
{
    Serial.begin(115200);
    delay(1000);

    Serial.println("===== APPLICATION STARTED =====");

    // Door sensor
    //
    // INPUT_PULLUP:
    // LOW  -> switch closed -> door closed
    // HIGH -> switch open   -> door open
    pinMode(DOOR_SENSOR_PIN, INPUT_PULLUP);

    // NeoPixel
    strip.begin();
    strip.clear();
    strip.show();

    Serial.println("Setup complete ...");
}


// --------------------------------------------------
// Main loop
// --------------------------------------------------
void loop()
{
    int doorState = digitalRead(DOOR_SENSOR_PIN);

    // Door CLOSED
    if (doorState == LOW)
    {
        Serial.println("Door is closed");

        // BLUE
        setLedColor(0, 0, 255);
    }

    // Door OPEN
    else
    {
        Serial.println("Door is open");

        // RED
        setLedColor(255, 0, 0);
    }

    delay(100);
}

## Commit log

2026-05-09 debug LED
2026-05-09 Demo of using bultin LED to display error scenario
2026-05-09 LED now uses RGB
2026-05-12 Add door sensor
2026-05-12 Experiment LED strip
2026-08-16 Case AI instructions
2026-10-04 Replicated scad
    [alarm_case2.scad, camera_angle_gauge.stl, camera_cradle.stl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]
2026-10-04 Verification scripts
    [alarm_case2.scad, camera_angle_gauge.stl, camera_cradle.stl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]
2026-10-04 remove verification output
    [camera_angle_gauge.stl, camera_cradle.stl, dupont_insert_2pin.stl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]
2026-10-04 LED change color when door change
    [alarm_case2.scad]
2026-10-04 Correct sizing of board bed
    [alarm_case2.scad]
2026-10-04 wall mount 20 degrees
    [alarm_case2.scad]
2026-10-04 wall mount
    [alarm_case2.scad]
2026-10-24 Only allow a set of RFID tags to arm/disarm
2026-10-24 Led implementation
2026-10-24 Cache ESP32 libraries
2026-10-24 Provide adafruit neopixel implementation for LED setting
